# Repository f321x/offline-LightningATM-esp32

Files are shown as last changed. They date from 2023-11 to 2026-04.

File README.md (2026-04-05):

# DEPRECATED
This project has been replaced by a new implementation in https://github.com/f321x/offline-bitcoin-atm

# offline-LightningATM-esp32
Bitcoin ATM (coins only) with lightning network support, running offline on an esp32. 
The lightning network is a 2nd layer protocol on top of the bitcoin protocol enabling trustless transactions with instant settlement and cheap fees.

## Special thanks to
@21isenough and contributors for the 3d models and inspiration  
[RPi based Lightning ATM repo](https://github.com/21isenough/LightningATM)

LNBits, Ben Arc and Stepan Snigirev for the cryptograpy used to make this ATM working without internet connection  
[Fossa ATM repository](https://github.com/lnbits/fossa) | [LNBits Homepage](https://lnbits.com/) | [uBitcoin library](https://github.com/micro-bitcoin/uBitcoin)

Axel Hamburch for the very detailed guide in german language on assembly of the electronics  
[Ereignishorizont Blog](https://ereignishorizont.xyz/lightning-atm/)

## Used parts
All the parts are available on eBay and Aliexpress

* ESP32 NodeMCU Dev Board | Any "normal" esp32 dev board should do the job here | [Example](https://web.archive.org/web/20231202141343/https://www.berrybase.de/en/esp32-nodemcu-development-board)
* DC-DC Adjustable Step-up Boost Power Supply LM2587S 5V -> 12V | for the coin acceptor, runs on 12V [Example](https://de.aliexpress.com/item/32834930982.html)
* Waveshare 1.54 inch e-Paper Display Modul with SPI Interface | [Example](https://www.waveshare.com/1.54inch-e-paper-module.htm)
* Programmable Coin Acceptor (HX-616) - 6 Coin | [Example](https://de.aliexpress.com/item/1005005203759184.html)
* 10mm Metal Push Button Switch 3-6V with Yellow LED, Self-reset Momentary | [Example](https://de.aliexpress.com/item/1005004527235094.html)
* USB Type C socket | to plug in the power supply (i used a Raspberry Pi type C power supply) [Example](https://de.aliexpress.com/item/1005005347655323.html)
* Little Mosfet modules ("15A 400W MOS FET Trigger") | To block the coin acceptor at certain points [Example](https://de.aliexpress.com/item/33038160184.html)
* Orange PLA Filament for the 3D Printer | [Example](https://us.polymaker.com/products/polylite-pla)
* Jumper Wires | [Example](https://de.aliexpress.com/item/1005005945668553.html)
* Heat-Set Threaded Inserts M3 | [Example](https://www.prusa3d.com/product/threaded-inserts-m3-standard-100-pcs/)

All in all would calculate around $100 for the neccessary parts

# Assembly Instructions for Lightning ATM

## 1. Connecting the Waveshare 1.54 inch Display to the ESP32

Begin by connecting the Waveshare display to the ESP32 using the following pin assignments:

| Display Pins | ESP32 GPIO |
|---|---|
| Busy | 27 |
| RST | 33 |
| DC | 25 |
| CS | 26 |
| CLK | SCK = 18 |
| DIN | MOSI = 23  |
| GND | GND |
| 3.3V | 3.3V |

## 2. Programming the Coin Acceptor

Ensure to adjust the voltage of the step-up converter before connecting the coin acceptor. Detailed programming instructions are available in the following guides:
- [Coin Acceptor Programming Guide (English)](https://github.com/21isenough/LightningATM/blob/master/docs/guide/coin_validator.md)
- [Coin Acceptor Programming Guide (German)](https://ereignishorizont.xyz/lightning-atm/)

## 3. Connecting the Coin Acceptor to the ESP32

- For the Coin <-> Pin 17 connection, use a cable as short as possible.
- Short circuit the two pins below the switch on the coin acceptor with the MOSFET on GND IN and GND OUT.
- Connect the MOSFET GND pin to the ESP32 GND and the PWM pin to the pin specified in `include/lightning_atm.h`.

| Periphery Pin | ESP32 GPIO |
|---|---|
| Coin Acceptor 'Coin Pin' | 17 |
| Mosfet PWM Pin | 16 |
| Mosfet GND Pin | GND |

## 4. Connecting the LED Button

Connect the LED Button to the ESP32 according to the pin assignments specified in `include/lightning_atm.h`:

| Periphery Pin | ESP32 GPIO |
|---|---|
| Button LED Pin (+) | 21 |
| Button LED Pin (-) | GND |
| Button PIN 1 | 32 |
| Button PIN 2 | GND |

For wiring inspiration and guidance, refer to [Lightning ATM Documentation](https://github.com/21isenough/LightningATM/tree/master/docs).

## 5. Circuit Diagram

Below are two possible wiring options. Depending on which ESP32 type and display / driver board you are using. 

1. Standard ESP32 with separate display / driver board

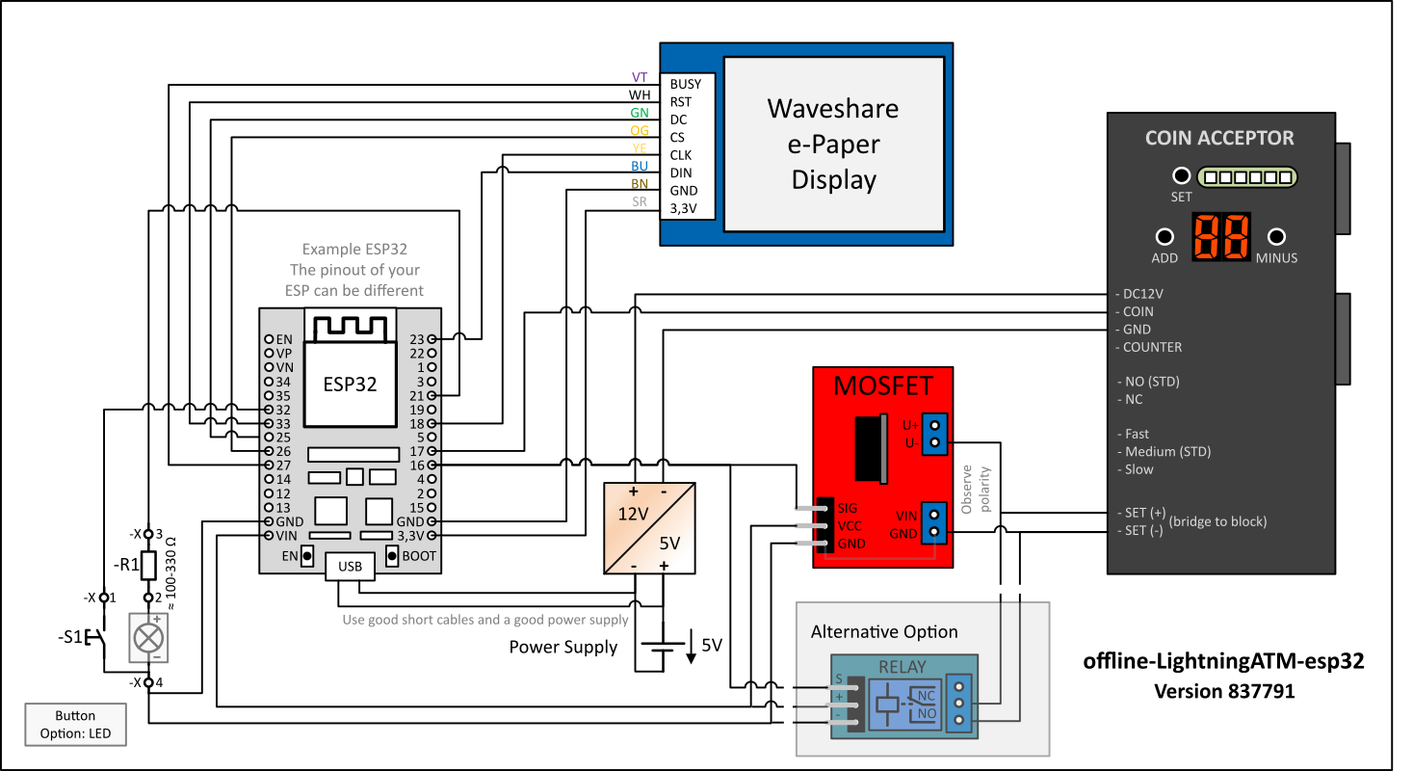
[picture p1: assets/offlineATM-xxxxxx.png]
Wiring - Circuit Diagram Normal ESP32


2. Waveshare ESP32 with integrated driver board and separate display

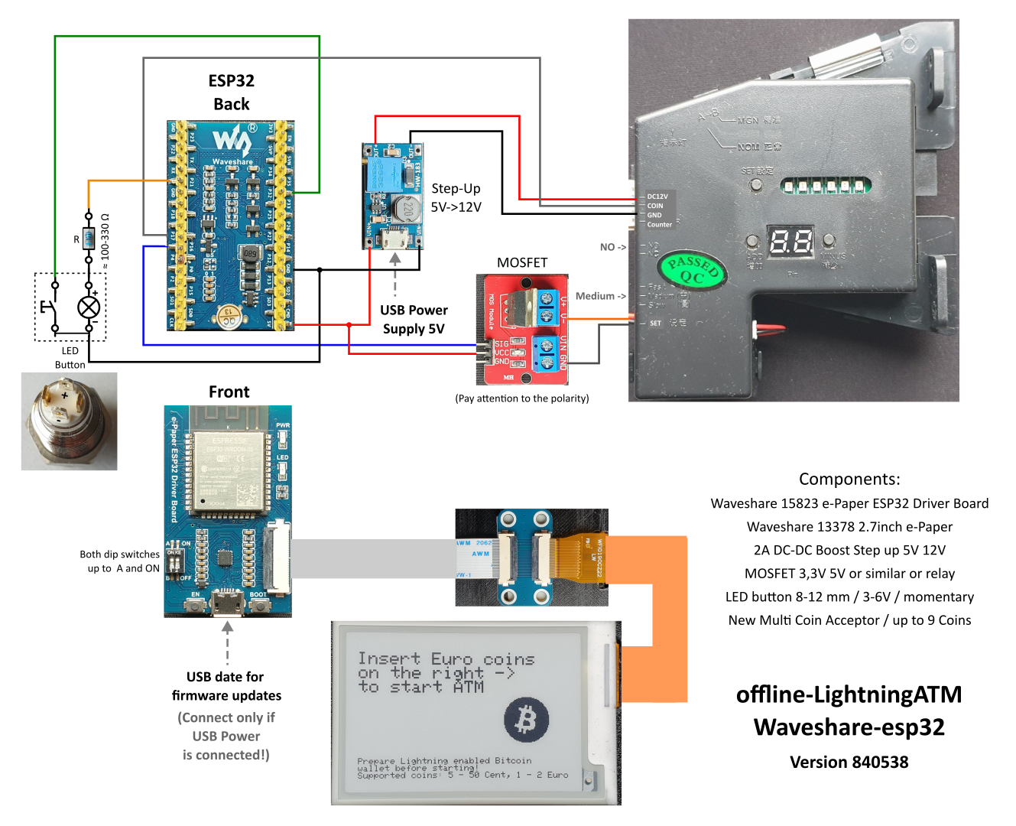
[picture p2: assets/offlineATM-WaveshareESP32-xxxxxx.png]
Wiring - Circuit Diagram Waveshare ESP32


## Setup software

1. Install VSCode and the PlattformIO IDE Extension.
2. Clone this repository and open it as PlattformIO Project.
3. Create an [LNbits](https://legend.lnbits.com/) wallet. Add the LNURLDevice extension and create a new LNURLDevice instance with ATM.

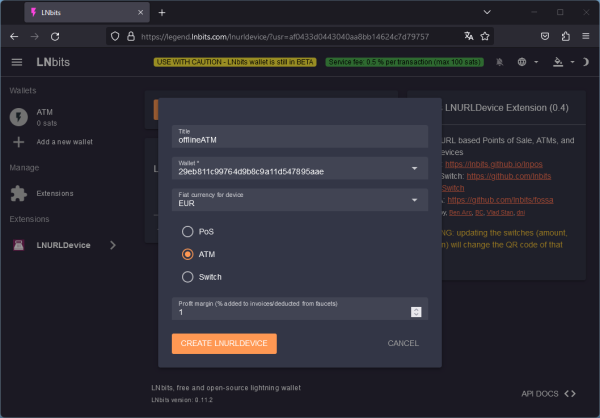
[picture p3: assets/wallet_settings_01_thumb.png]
wallet_settings_02_thumb
    

4. Copy the LNURLDevice Settings String and paste it into the code under “include/lighting_atm.h” under “USER ACTION”.

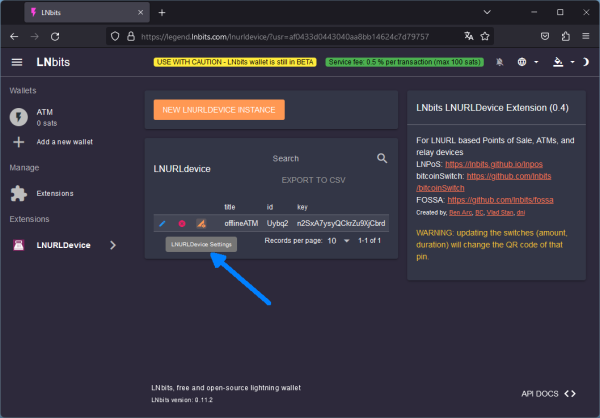
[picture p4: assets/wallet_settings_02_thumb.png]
wallet_settings_02_thumb
    

5. Flash the software on the esp32. You may have to disconnect the ESP32 from the step up converter before connecting it to the computer to prevent faults, or power it up with the power supply and use an usb isolator.

If you need help ask me on Nostr @npub1z9n5ktfjrlpyywds9t7ljekr9cm9jjnzs27h702te5fy8p2c4dgs5zvycf

If this software and guide provided value to you feel free to send some sats to x@lnaddress.com

## Images

Standard ESP32

PXL_20231126_162906807 MP_1

Waveshare ESP32
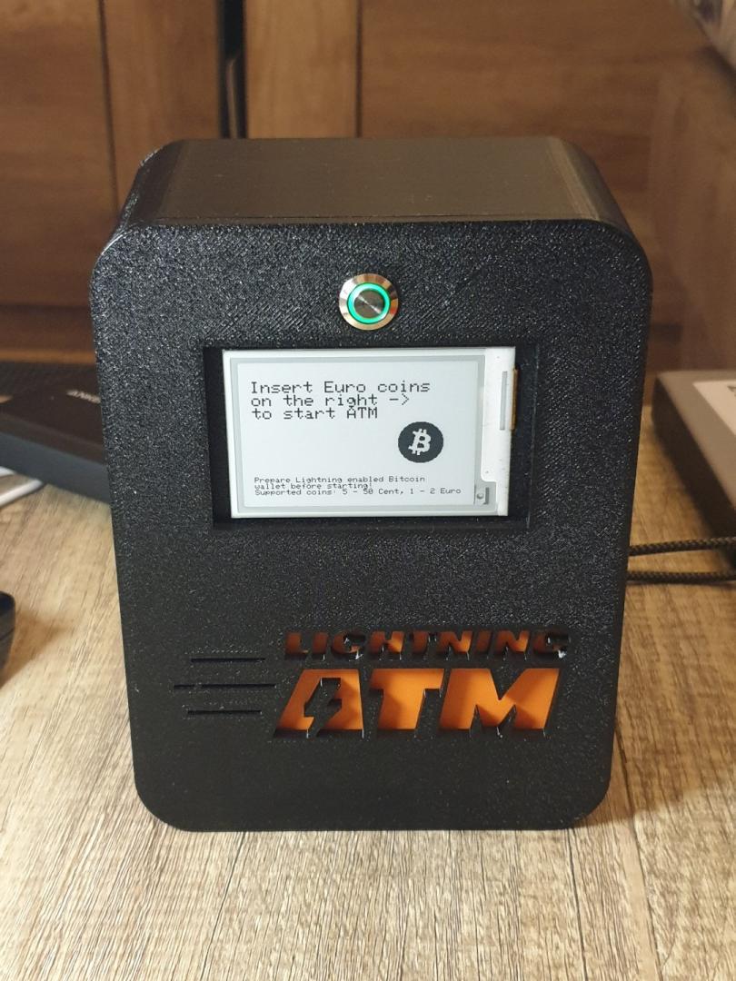
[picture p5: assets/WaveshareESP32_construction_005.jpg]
Construction - Waveshare ESP32

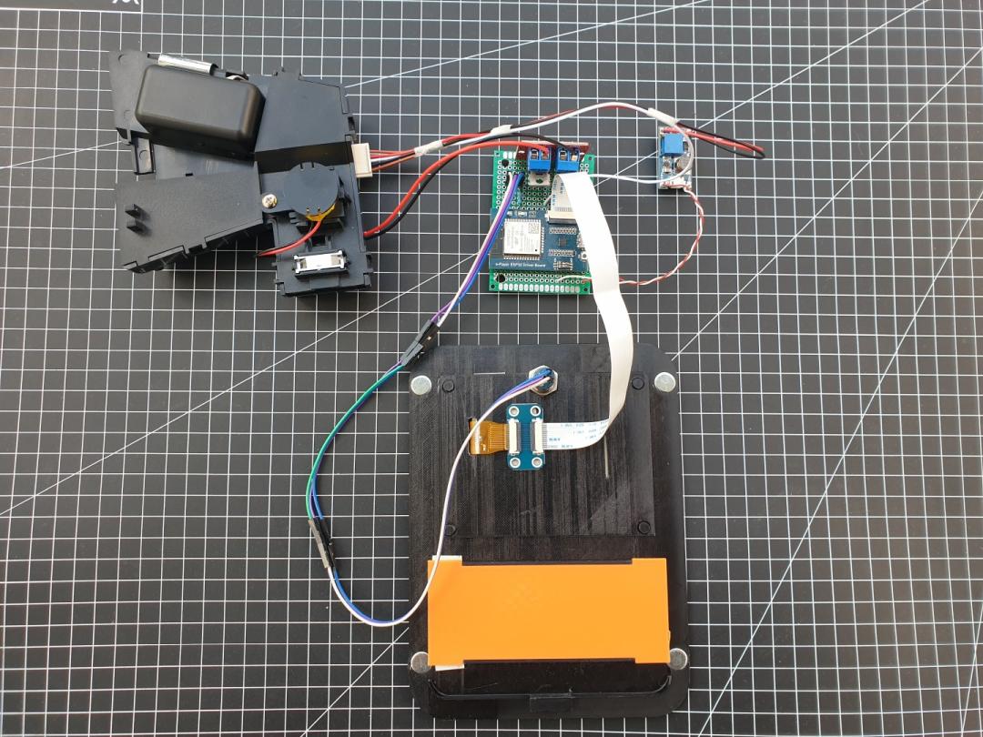
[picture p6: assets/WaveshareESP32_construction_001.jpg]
Construction - Waveshare ESP32

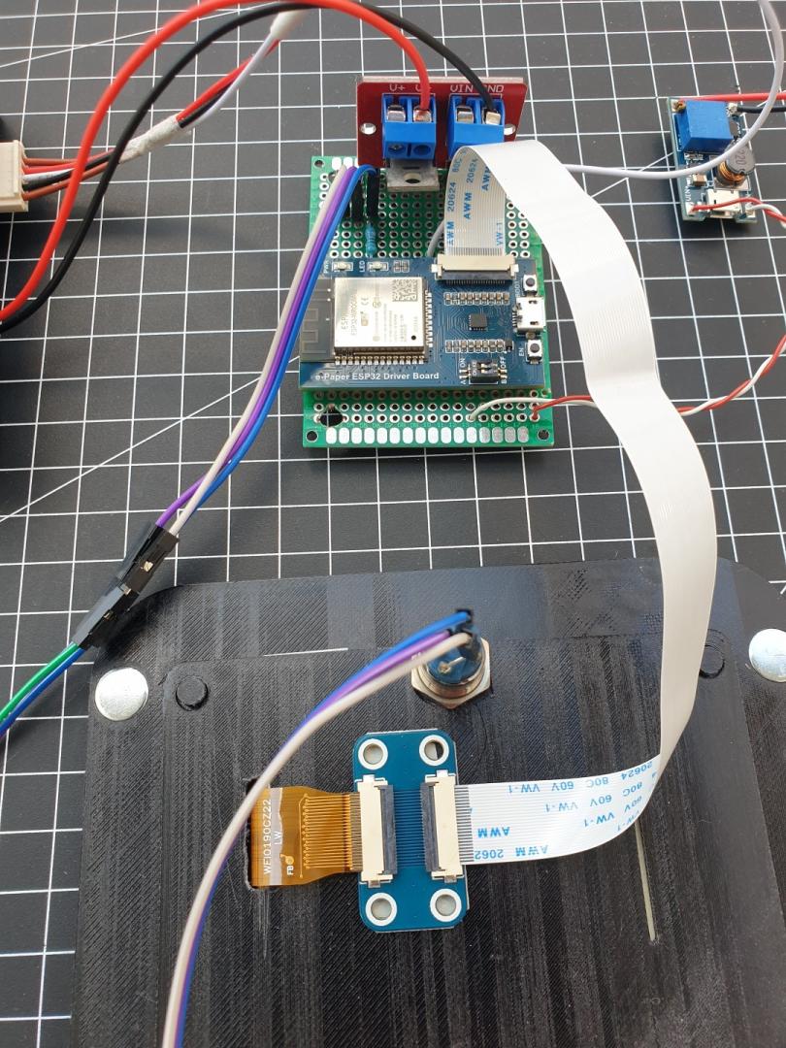
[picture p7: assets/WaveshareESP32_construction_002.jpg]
Construction - Waveshare ESP32

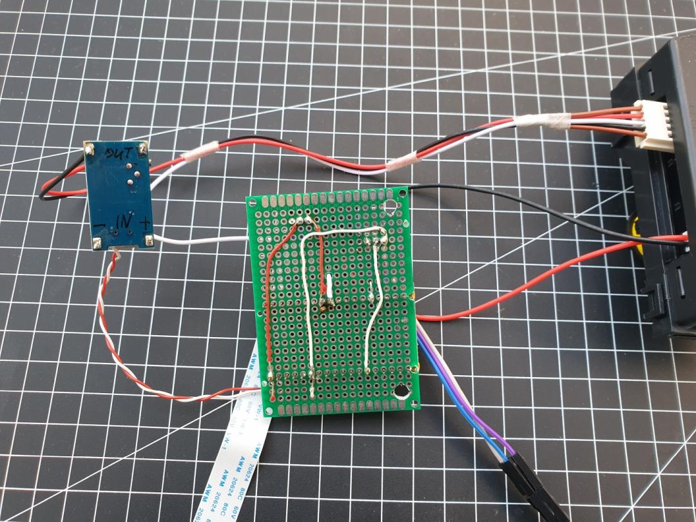
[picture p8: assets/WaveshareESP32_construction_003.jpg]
Construction - Waveshare ESP32

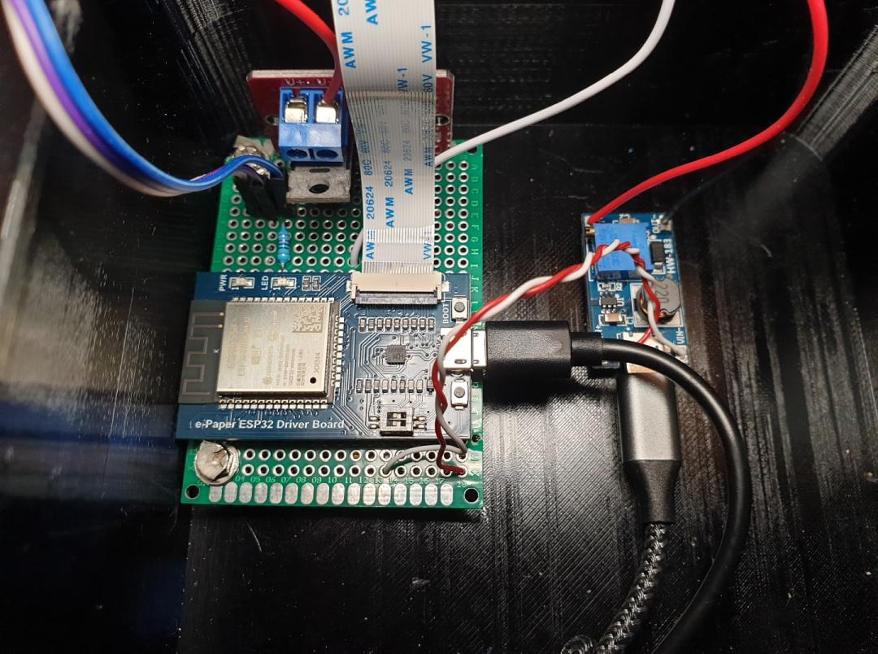
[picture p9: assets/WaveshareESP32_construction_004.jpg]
Construction - Waveshare ESP32


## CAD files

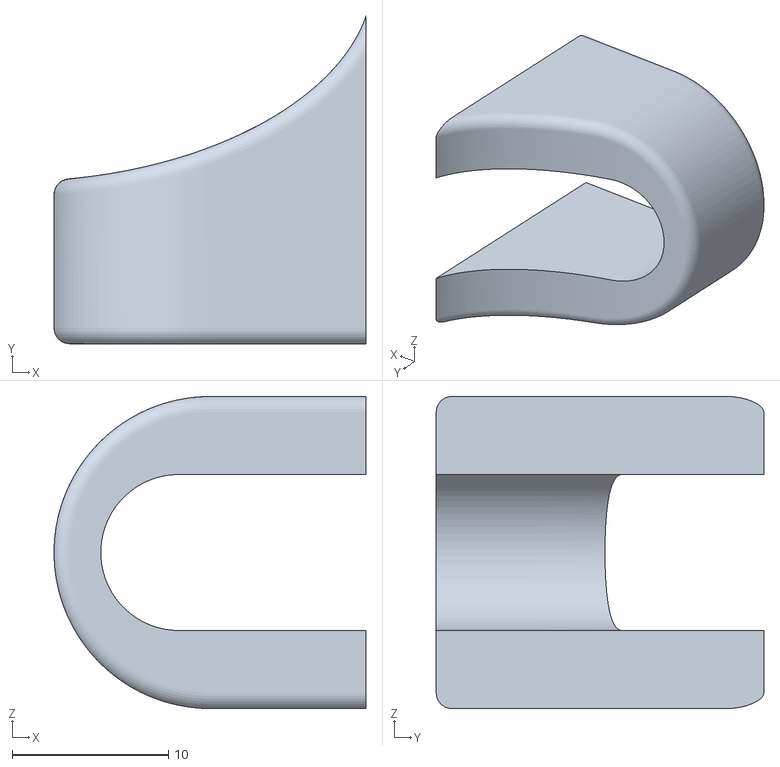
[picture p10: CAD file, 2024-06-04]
3d-print-model/CCatch v3.stl
20.0 x 21.0 x 20.0

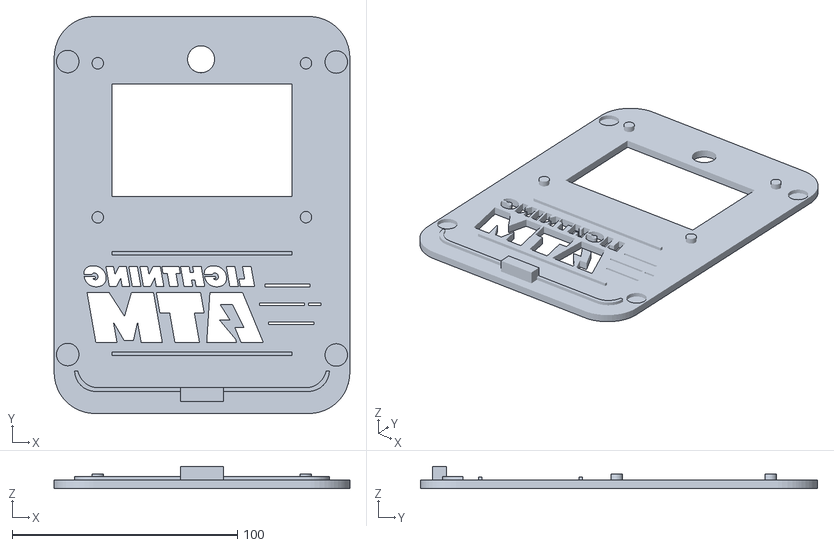
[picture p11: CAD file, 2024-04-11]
3d-print-model/Magnet Case - with button preferred/Front Magnet - with 12 mm hole.stl
131.2 x 176.2 x 9.96

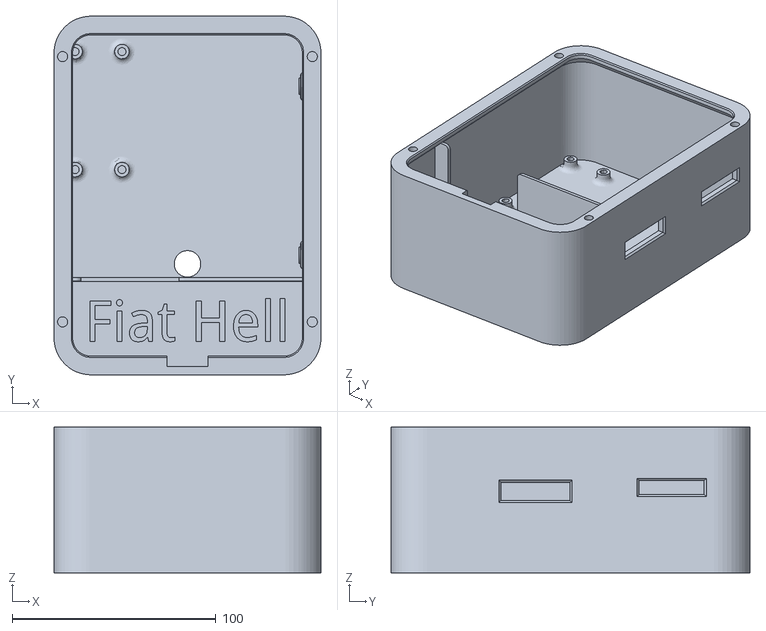
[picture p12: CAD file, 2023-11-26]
3d-print-model/Magnet Case - with button preferred/Case Magnet.stl
131.2 x 176.2 x 71.7

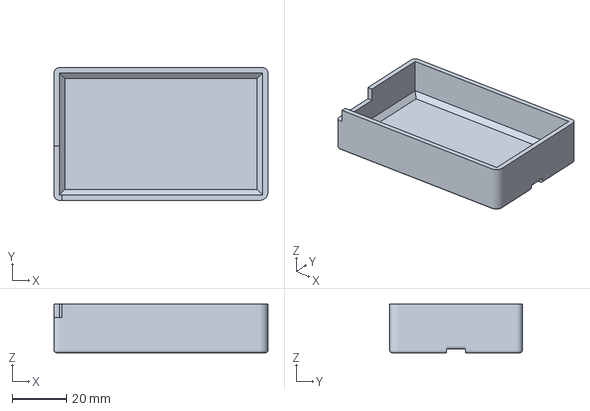
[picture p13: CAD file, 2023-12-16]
3d-print-model/transport_screen_cover.3mf
79.0 x 49.0 x 18.0 mm

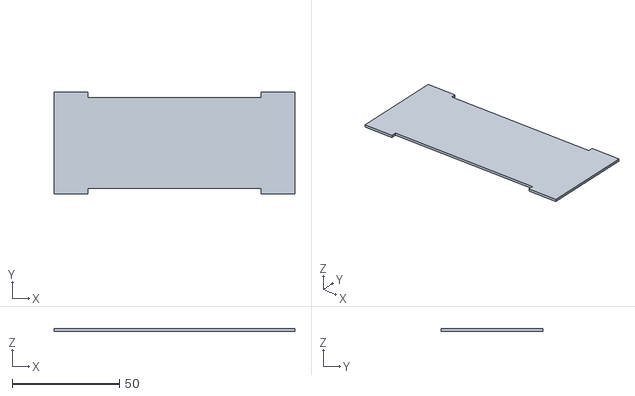
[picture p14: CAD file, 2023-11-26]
3d-print-model/Magnet Case - with button preferred/Logo Backplate Magnet.stl
112.3 x 47.6 x 1.20

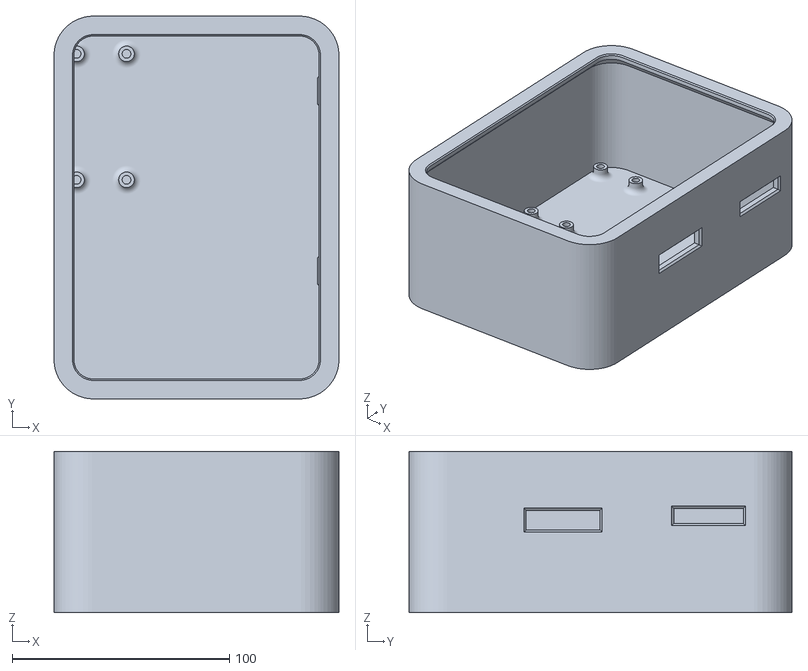
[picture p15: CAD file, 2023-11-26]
3d-print-model/Shell_v1_NoSupp.stl
131.2 x 176.2 x 74.2

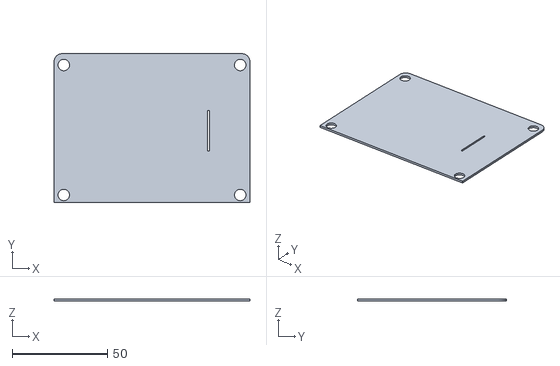
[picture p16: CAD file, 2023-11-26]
3d-print-model/Magnet Case - with button preferred/Screen Backplate Magnet.stl
103.0 x 78.1 x 1.20

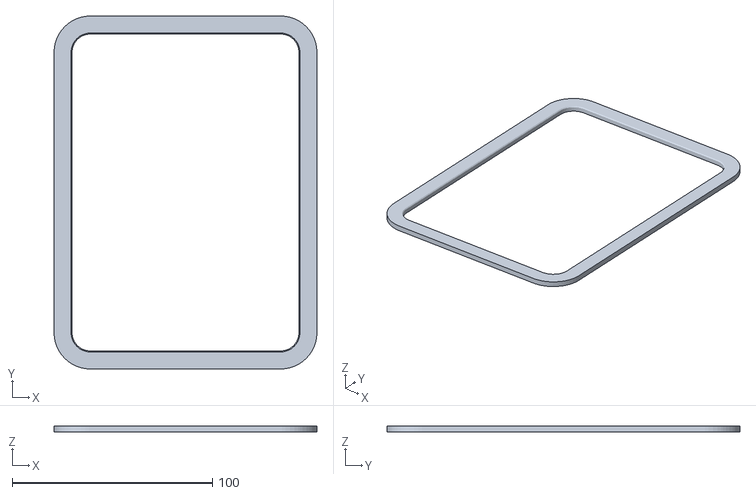
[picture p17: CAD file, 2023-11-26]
3d-print-model/optional_Mounting_Rim_v1_NoSupp.stl
131.2 x 176.2 x 3.00

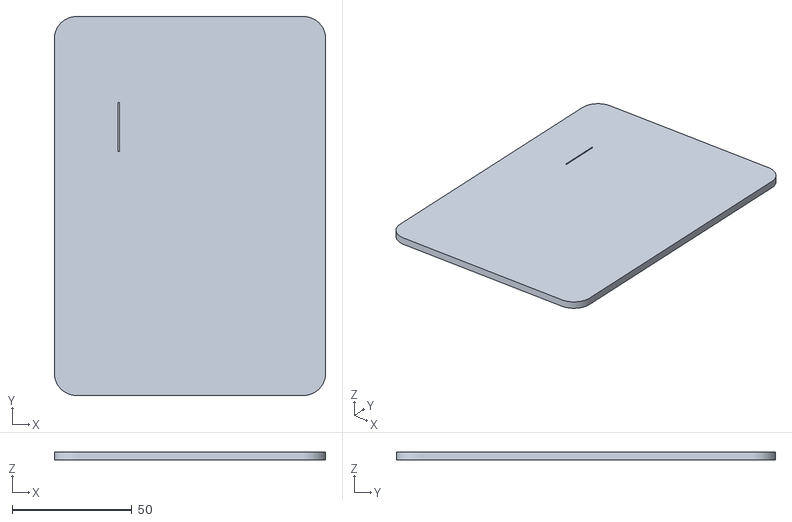
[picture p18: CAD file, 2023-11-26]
3d-print-model/Back_Lid_THICKER_v1_NoSupp.stl
113.4 x 158.4 x 3.50

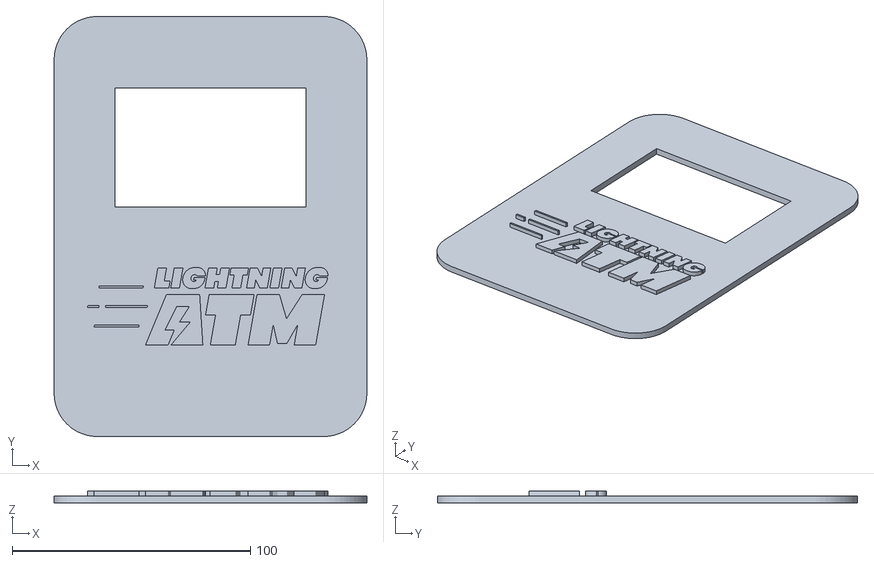
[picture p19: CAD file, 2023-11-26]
3d-print-model/Top_Lid_with_Logo_v1_NoSupp.stl
131.2 x 176.2 x 5.00

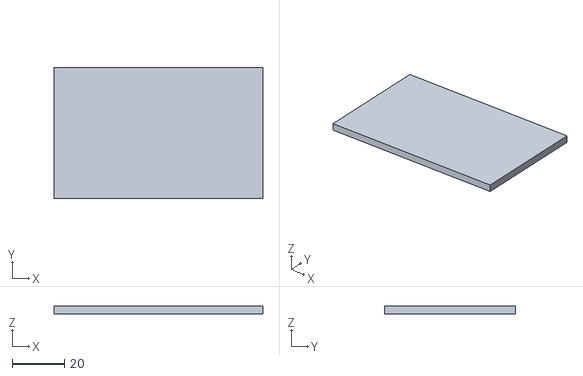
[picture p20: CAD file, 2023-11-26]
3d-print-model/Front_Glass_v1_NoSupp.stl
80.2 x 50.2 x 3.00

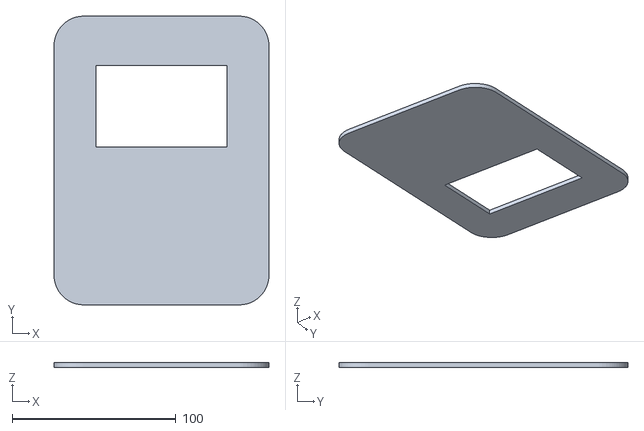
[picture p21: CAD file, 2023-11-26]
3d-print-model/Top_Lid_No_Logo_v1_NoSupp.stl
131.2 x 176.2 x 3.00

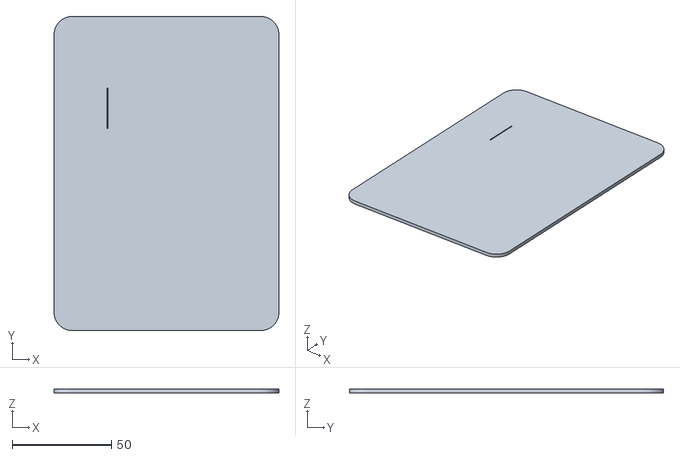
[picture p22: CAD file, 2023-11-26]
3d-print-model/Back_Lid_NORMAL_v1_NoSupp.stl
113.4 x 158.4 x 2.00

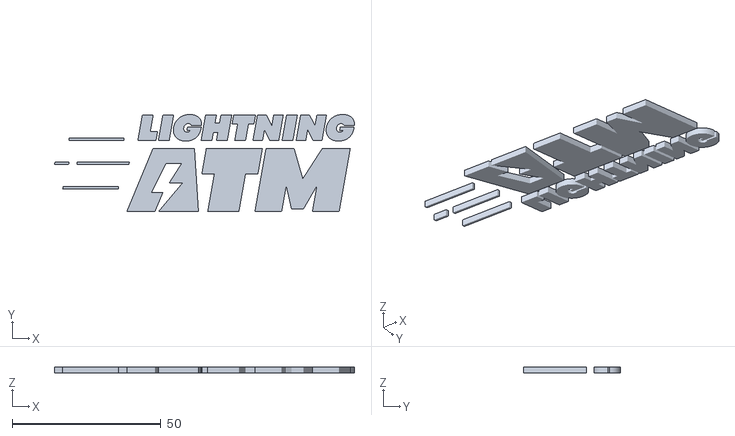
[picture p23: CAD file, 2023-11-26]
3d-print-model/just_logo.stl
100.9 x 32.6 x 2.00

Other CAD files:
3d-print-model/Magnet Case/Front Magnet.stl

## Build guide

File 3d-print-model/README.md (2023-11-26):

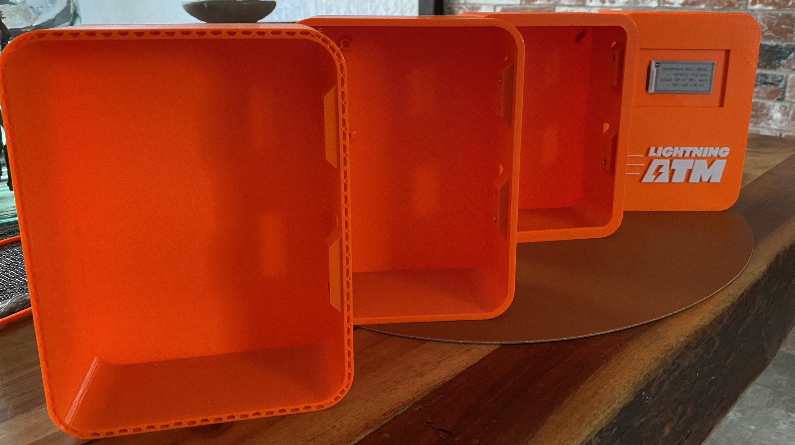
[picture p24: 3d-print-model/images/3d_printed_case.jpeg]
 <br>

# 3D Printed L-ATM Case PE-Edition

Below files can be used to print a case, which lowers your overall costs. The models can be printed  without any supports.

This is the first version and is designed to be used with inserts to mount the Coin-Acceptor as well as the Rasbperry-Pi Zero. For the Coin Acceptor use **M3** inserts [(Amazon)](https://amzn.to/35eNkgj), for the Raspberry-Pi **M2.5** [(Amazon)](https://amzn.to/2HjF0Uo) inserts are needed.
The Lids holds by friction fit.

For the case **needed** are 3 Parts: 
- **Shell**
  
- **Back Lid**
  - two versions
    - normal with 2mm thick plate
    - thicker with 3mm thick plate
- **Top Lid**
  - there are two separate versions:
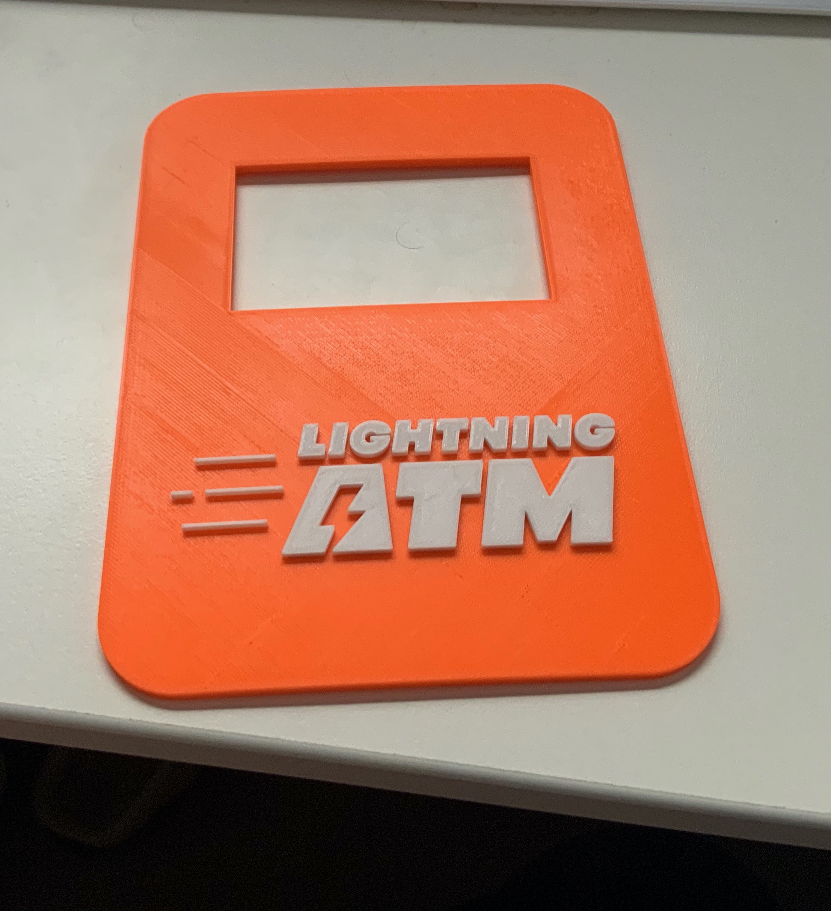
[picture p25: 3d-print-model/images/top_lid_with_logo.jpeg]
    - with Lightning-Logo, *for dual color print add a **color change at Z 3.00 mm***. 
    - without any logo
- Mounting Rim
  - optional but *recommended* to properly glue the Top Lid onto the Back Lid.

1. Print Shell / Back Lid / Top Lid / Mounting Rim
2. Use soldering iron to:
   1. Add M3 Inserts into Coin Acceptor holes 
   2. Add M2.5 Inserts into Raspberry holes
   
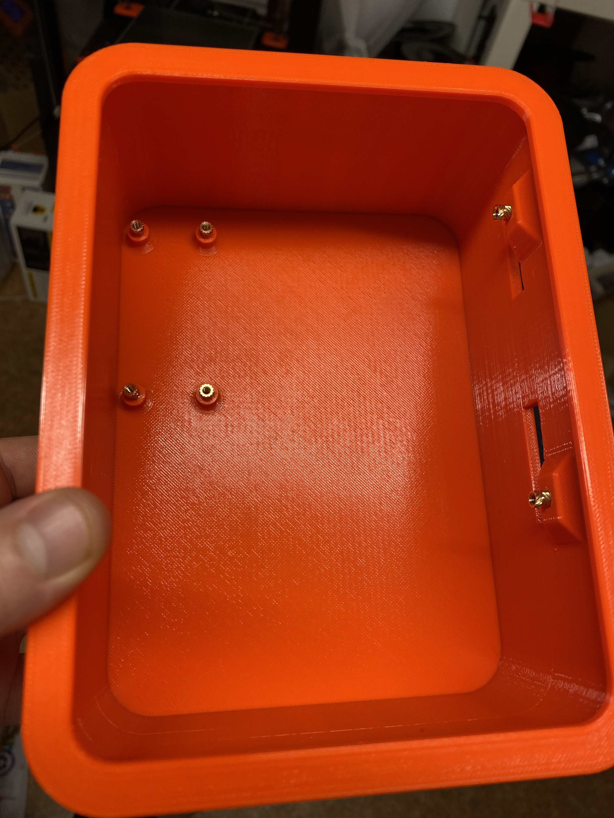
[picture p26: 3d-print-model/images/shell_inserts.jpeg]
   <br> <br>
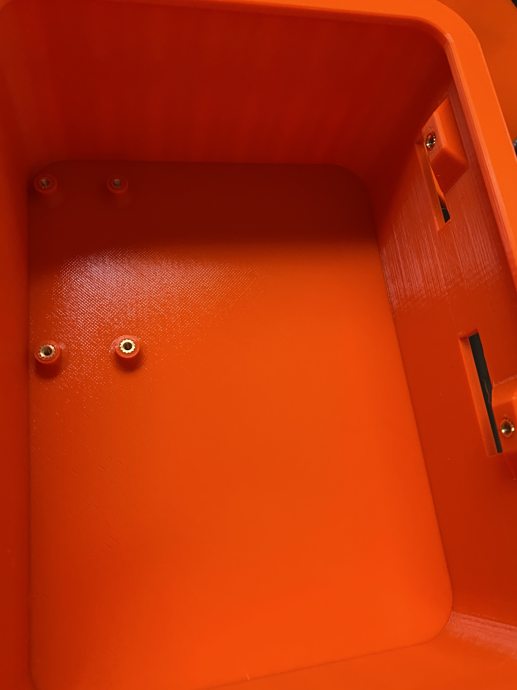
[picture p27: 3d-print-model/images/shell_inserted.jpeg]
   
   
3. If you have printed the *Mounting Rim* put it around the BackLid
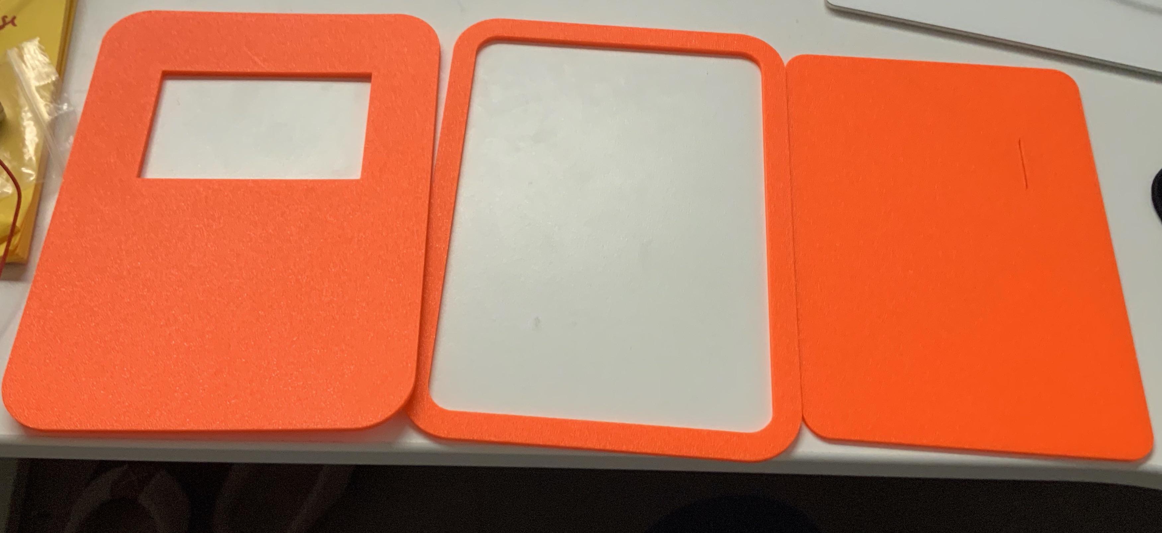
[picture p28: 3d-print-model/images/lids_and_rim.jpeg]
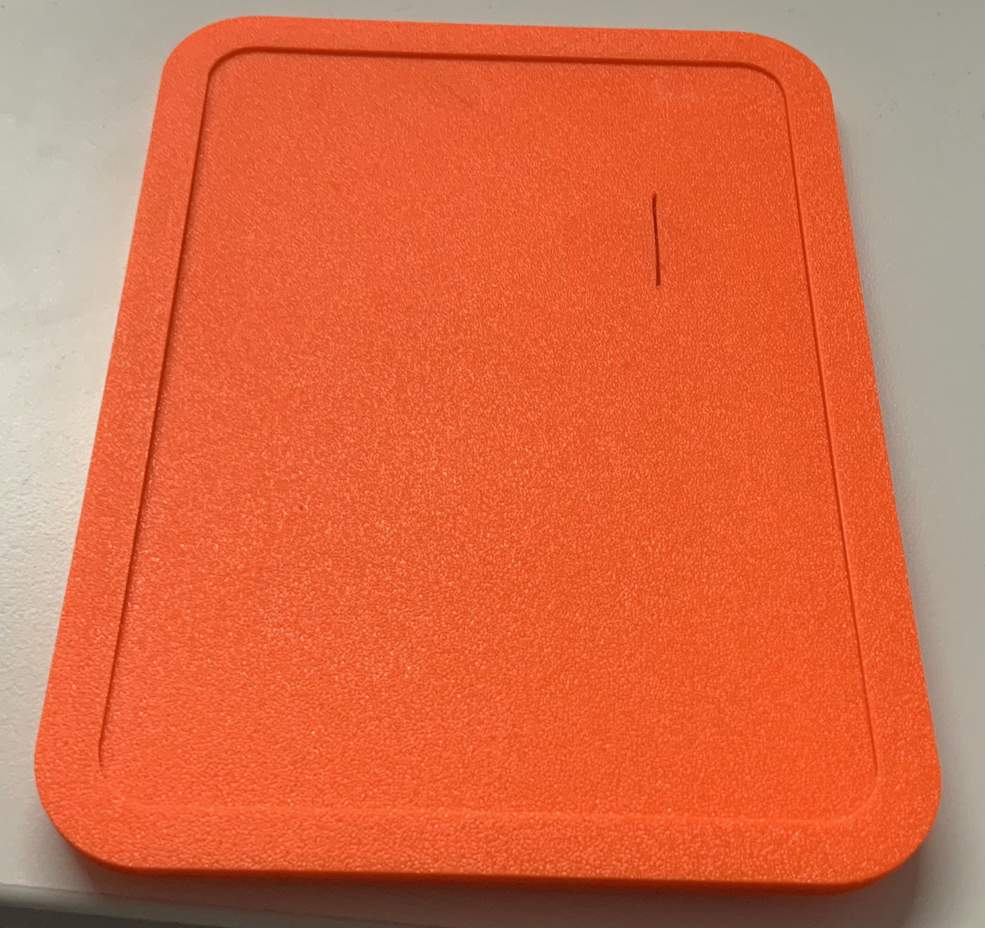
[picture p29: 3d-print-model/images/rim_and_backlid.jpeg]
<br> <br> 
4. put glue on the Top Lid and use something to press both together
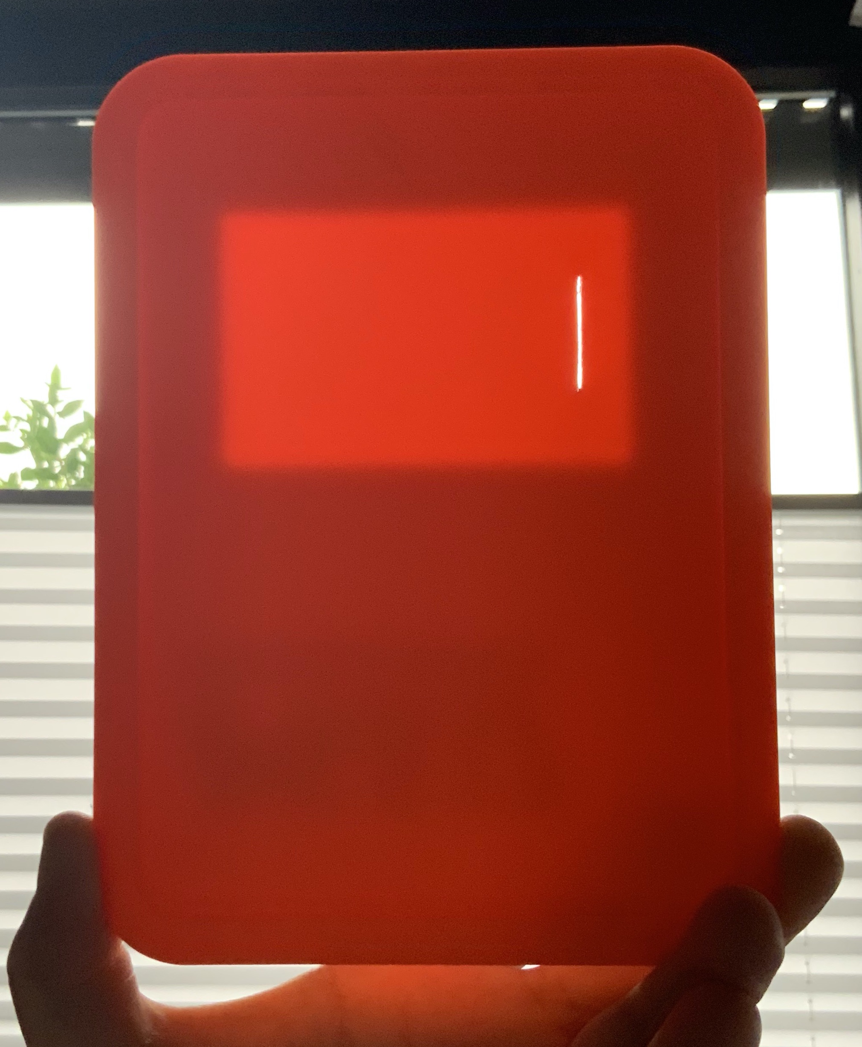
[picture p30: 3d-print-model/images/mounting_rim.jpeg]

5. this is what it should look like without the rim
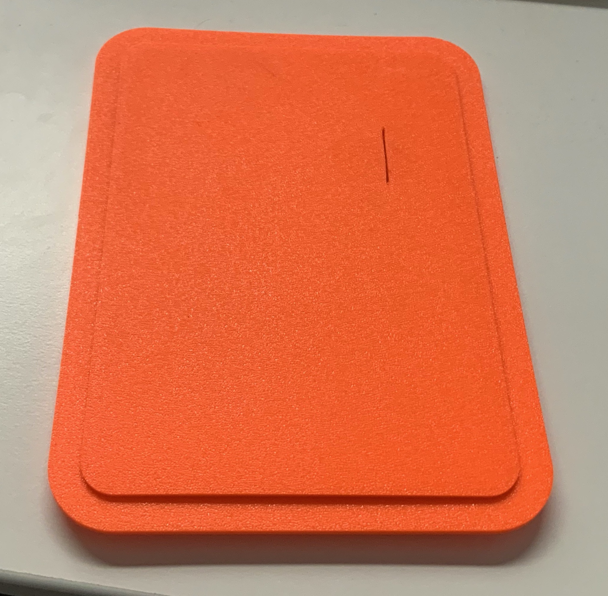
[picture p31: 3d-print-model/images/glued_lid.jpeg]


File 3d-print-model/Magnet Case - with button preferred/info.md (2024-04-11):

I have added new 3D models, which can be supplemented with magnets so that you no longer have to attach the front panel to the case with a rubber band. You can find the procedure and more details in my Twitter Thread ...

Magnets: 5x5mm round nickel plate: https://www.supermagnete.ch/scheibenmagnete-neodym/scheibenmagnet-5mm-5mm_S-05-05-N
Metal plates: 2x10mm self-adhesive: https://www.supermagnete.ch/magnethaftgruende-selbstklebend/metallscheiben-selbstklebend-10mm_PAS-10

For more information please DM me on Twitter or Telegram! @Nicolas_b58

Update axelhamburch 838776:
In this version, the front panel has a hole for a 12 mm LED button in the upper area of the front panel. You will need a drill and possibly a file for the "screen backplate". Depending on which display you use, you may also need this for a feed-through for the ribbon cable.

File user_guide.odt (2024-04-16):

Lightning ATM guide

What is „Lightning“?

Lightning is a protocol layer on top of the Bitcoin protocol, like HTTP on TCP/IP, enabling instant, trustless and cheap bitcoin transactions.

How to use Lightning⚡?

You need a Bitcoin Wallet that supports the Lightning protocol. There are many different ones for various use cases. You can hold your own private keys, which is recommended for more advanced users (e.g. “Phoenix Wallet”) but involves higher setup cost, or use a trusted, convenient service.

For the beginning go to mutinywallet.com and download the app. Select a federation, save the backup words on a piece of paper and you’re set!

How to use the ATM?

Insert Euro coins >= 5ct, press button once done, scan QR code, done!

1 Satoshi == 0.00000001 ₿

Problems😡

Contact XXX, i’ll fix it.

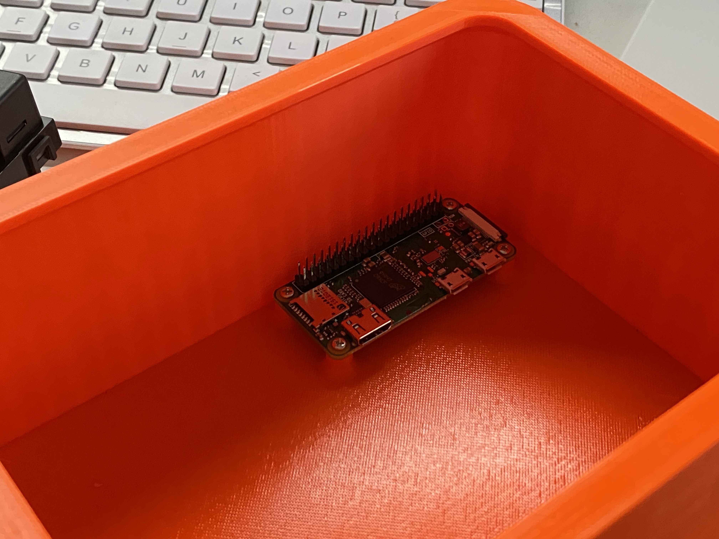
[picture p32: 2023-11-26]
3d-print-model/images/shell_with_mounted_pi.jpeg

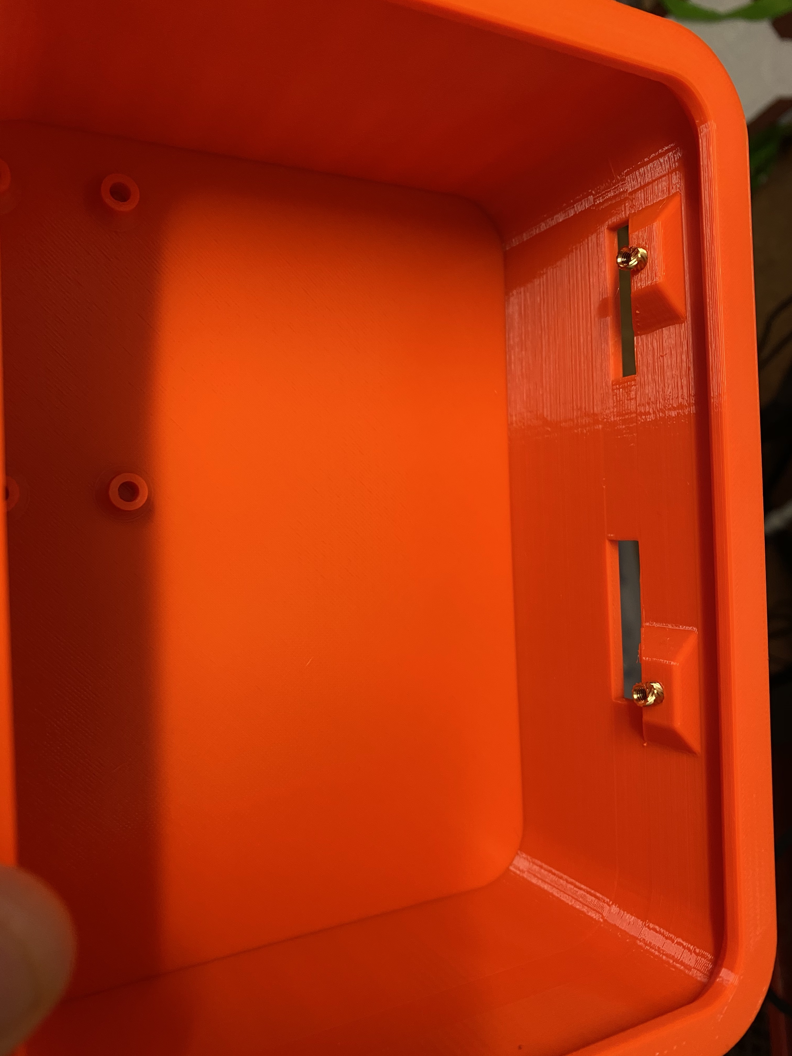
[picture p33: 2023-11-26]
3d-print-model/images/shell_m3_inserts.jpeg

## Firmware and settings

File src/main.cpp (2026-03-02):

#include "lightning_atm.hpp"

const unsigned int COINS[] = { 0, 0, 5, 10, 20, 50, 100, 200, 1, 2 };
bool button_pressed = false;
unsigned int inserted_cents = 0;
unsigned long long time_last_press = millis();
String baseURLATM;
String secretATM;
String currencyATM;
bool fossaMode = false;  // set automatically from lnurlDeviceString in setup()

// *** for Waveshare ESP32 Driver board *** //
#if defined(ESP32) && defined(USE_HSPI_FOR_EPD)
SPIClass hspi(HSPI);
#endif
// *** end Waveshare ESP32 Driver board *** //


void setup()
{
  initialize_display(); // connection to the e-ink display
  Serial.begin(9600);
  // *** for Waveshare ESP32 Driver board *** //
#if defined(ESP32) && defined(USE_HSPI_FOR_EPD)
  hspi.begin(13, 12, 14, 15); // remap hspi for EPD (swap pins)
  display.epd2.selectSPI(hspi, SPISettings(4000000, MSBFIRST, SPI_MODE0));
#endif
  // *** end Waveshare ESP32 Driver board *** //
  if (DEBUG_MODE)                                           // serial connection for debugging over USB
  {
    sleep(3);
    Serial.println("Setup with debug mode...");             // for monitoring with serial monitor to debug
    Serial.println("Selected display type: " + display_type);
  }
  pinMode(COIN_PIN, INPUT_PULLUP);                          // coin acceptor input
  pinMode(LED_BUTTON_PIN, OUTPUT);                          // LED of the LED Button
  pinMode(BUTTON_PIN, INPUT_PULLUP);                        // Button
  pinMode(MOSFET_PIN, OUTPUT);                              // mosfet relay to block the coin acceptor
  digitalWrite(MOSFET_PIN, LOW);                            // set it low to accept coins, high to block coins
  attachInterrupt(BUTTON_PIN, button_pressed_itr, FALLING); // interrupt, will set button_pressed to true when button is pressed
  home_screen();                                            // will show first screen
  digitalWrite(LED_BUTTON_PIN, HIGH);                       // light up the led
  baseURLATM = getValue(lnurlDeviceString, ',', 0);         // setup wallet data from string
  secretATM = getValue(lnurlDeviceString, ',', 1);
  currencyATM = getValue(lnurlDeviceString, ',', 2);
  fossaMode = (lnurlDeviceString.indexOf("/fossa/") >= 0); // auto-detect backend from URL
}

void loop()
{
  unsigned int pulses = 0;
  unsigned long long time_last_press;

  pulses = detect_coin(); // detect_coin() is a loop to detect the input of coins, will return the amount of pulses
  if (pulses >= 2 && pulses <= 9)
  {
    digitalWrite(MOSFET_PIN, HIGH);
    digitalWrite(LED_BUTTON_PIN, LOW);
    inserted_cents += COINS[pulses];
    show_inserted_amount(inserted_cents);
  }
  else if (button_pressed && inserted_cents > 0)
  {
    digitalWrite(MOSFET_PIN, HIGH);
    button_pressed = false;
    try {
      // makeLNURL can raise
      String lnurl = makeLNURL(inserted_cents);
      qr_withdrawl_screen(lnurl.c_str());
      wait_for_user_to_scan();
    }
    catch (const std::exception& e) {
      Serial.println(e.what());
    }
    digitalWrite(LED_BUTTON_PIN, HIGH);
    home_screen();
    digitalWrite(MOSFET_PIN, LOW);
    inserted_cents = 0;
  }
  else if (button_pressed && !pulses && !inserted_cents) // to clean the screen (for storage), press the button several times
  {
    int press_counter = 0;

    button_pressed = false;
    time_last_press = millis();
    while ((millis() - time_last_press) < 4000 && press_counter < 6)
    {
      if (button_pressed)
      {
        if (DEBUG_MODE)
          Serial.println("Button pressed");
        time_last_press = millis();
        button_pressed = false;
        press_counter++;
        delay(500);
      }
    }
    if (press_counter > 5)
    {
      if (DEBUG_MODE)
        Serial.println("Button pressed over 5 times, will clean screen...");
      digitalWrite(LED_BUTTON_PIN, LOW);
      clean_screen();
      display_sleep();
      delay(30000);
      home_screen();
    }
  }
}

// function to handle the button interrupt
void IRAM_ATTR button_pressed_itr()
{
  button_pressed = true;
}

// blocking loop which is called when the qr code is shown
void wait_for_user_to_scan()
{
  unsigned long long time;
  bool light_on;

  if (DEBUG_MODE)
    Serial.println("Waiting for user to scan qr code and press button...");
  light_on = true;
  time = millis();  // save start time
  digitalWrite(LED_BUTTON_PIN, HIGH);  // light up the led
  delay(5000);
  button_pressed = false;
  Serial.println("wait for user to press button or 10 minutes to go back to home screen");
  while (!button_pressed && (millis() - time) < 600000)
  {
    if (!light_on && (millis() - time) > 30000)
    {
      digitalWrite(LED_BUTTON_PIN, HIGH);
      light_on = true;
    }
    else if (light_on && (millis() - time) > 30000)
    {
      digitalWrite(LED_BUTTON_PIN, LOW);
      light_on = false;
    }
    delay(500);
  }
  Serial.println("Exit waiting");
}

unsigned int detect_coin()
{
  unsigned long last_pulse;
  unsigned int pulses;
  bool prev_value;
  bool read_value;
  unsigned long entering_time;
  unsigned long current_time;

  if (DEBUG_MODE)
    Serial.println("Starting coin detection...");
  pulses = 0;
  read_value = 1;
  prev_value = digitalRead(COIN_PIN);
  digitalWrite(LED_BUTTON_PIN, HIGH);
  digitalWrite(MOSFET_PIN, LOW);
  button_pressed = false;
  entering_time = millis();
  while (true && !button_pressed)
  {
    read_value = digitalRead(COIN_PIN);
    if (read_value != prev_value && !read_value)
    {
      delay(35);
      read_value = digitalRead(COIN_PIN);
      if (!read_value)
      {
        pulses++;
        last_pulse = millis();
        digitalWrite(MOSFET_PIN, HIGH);
      }
    }
    prev_value = read_value;
    current_time = millis();
    if (pulses > 0 && (current_time - last_pulse > PULSE_TIMEOUT))
    {
      break;
    }
    else if (pulses == 0 && ((current_time - entering_time) > 43200000) // refreshes the screen every 12h
      && inserted_cents == 0)
    {
      clean_screen();
      delay(10000);
      entering_time = millis();
      home_screen();
    }
    else if (inserted_cents > 0 && (current_time - entering_time) > 360000) // break the loop if no new coin is inserted for some time
      button_pressed = true;
  }
  if (DEBUG_MODE)
    Serial.println("Pulses: " + String(pulses));
  if (button_pressed)
  {
    if (DEBUG_MODE)
      Serial.println("Button pressed, stopping coin detection");
    return (0);
  }
  return (pulses);
}

/*
** DISPLAY UTILS
*/

// sleep is to put the screen in hibernation mode for longer static frames
void display_sleep()
{
  if (display_type == "GxEPD2_150_BN")
    display.hibernate();
  else if (display_type == "GxEPD2_270")
    display.hibernate();
  else if (display_type == "GxEPD2_270_GDEY027T91")
    display.hibernate();
  else if (display_type == "GxEPD2_213_B74")
    display.hibernate();
  else if (display_type == "GxEPD2_213_flex")
    display.hibernate();
  else
    Serial.println("No suitable display class defined.");
}

void initialize_display()
{
  if (display_type == "GxEPD2_150_BN")
    display.init(115200, true, 2, false);
  else if (display_type == "GxEPD2_270")
    display.init(115200, true, 2, false);
  else if (display_type == "GxEPD2_270_GDEY027T91")
    display.init(115200, true, 2, false);
  else if (display_type == "GxEPD2_213_B74")
    display.init(115200, true, 2, false);
  else if (display_type == "GxEPD2_213_flex")
    display.init(115200, true, 2, false);
  else
    Serial.println("No suitable display class defined.");
}

void home_screen()
{
  if (display_type == "GxEPD2_150_BN")
    home_screen_waveshare_1_54();
  else if (display_type == "GxEPD2_270")
    home_screen_waveshare_2_7();
  else if (display_type == "GxEPD2_270_GDEY027T91")
    home_screen_waveshare_2_7();
  else if (display_type == "GxEPD2_213_B74")
    home_screen_waveshare_2_13();
  else if (display_type == "GxEPD2_213_flex")
    home_screen_waveshare_2_13_flex();
  else
    Serial.println("No suitable display class defined.");
  if (DEBUG_MODE)
    Serial.println("Home screen printed.");
}

void show_inserted_amount(int amount_in_cents)
{
  String amount_in_euro_string;

  amount_in_euro_string = get_amount_string(amount_in_cents);
  if (display_type == "GxEPD2_150_BN")
    show_inserted_amount_waveshare_1_54(amount_in_euro_string);
  else if (display_type == "GxEPD2_270")
    show_inserted_amount_waveshare_2_7(amount_in_euro_string);
  else if (display_type == "GxEPD2_270_GDEY027T91")
    show_inserted_amount_waveshare_2_7(amount_in_euro_string);
  else if (display_type == "GxEPD2_213_B74")
    show_inserted_amount_waveshare_2_13(amount_in_euro_string);
  else if (display_type == "GxEPD2_213_flex")
    show_inserted_amount_waveshare_2_13_flex(amount_in_euro_string);
  else
    Serial.println("No suitable display class defined.");
  if (DEBUG_MODE)
    Serial.println("New amount on screen.");
}

void qr_withdrawl_screen(const char* qr_content)
{
  if (display_type == "GxEPD2_150_BN")
    qr_withdrawl_screen_waveshare_1_54(qr_content);
  else if (display_type == "GxEPD2_270")
    qr_withdrawl_screen_waveshare_2_7(qr_content);
  else if (display_type == "GxEPD2_270_GDEY027T91")
    qr_withdrawl_screen_waveshare_2_7(qr_content);
  else if (display_type == "GxEPD2_213_B74")
    qr_withdrawl_screen_waveshare_2_13(qr_content);
  else if (display_type == "GxEPD2_213_flex")
    qr_withdrawl_screen_waveshare_2_13_flex(qr_content);
  else
    Serial.println("No suitable display class defined.");
  if (DEBUG_MODE)
    Serial.println("QR generated and Withdrawl screen printed.");
}


//  Called to clean the e-ink screen for storage over longer periods 
// by button presses on home screen
void clean_screen()
{
  if (DEBUG_MODE)
    Serial.println("Cleaning screen...");
  if (display_type == "GxEPD2_150_BN")
    clean_screen_waveshare_1_54();
  else if (display_type == "GxEPD2_270")
    clean_screen_waveshare_2_7();
  else if (display_type == "GxEPD2_270_GDEY027T91")
    clean_screen_waveshare_2_7();
  else if (display_type == "GxEPD2_213_B74")
    clean_screen_waveshare_2_13();
  else if (display_type == "GxEPD2_213_flex")
    clean_screen_waveshare_2_13_flex();
  else
    Serial.println("No suitable display class defined.");
}

// converts a cent amount to a String like "1.15 Euro"
String get_amount_string(int amount_in_cents)
{
  String euro;
  String cents;
  String return_value;
  int euro_value;
  int cent_remainder;

  euro_value = amount_in_cents / 100;
  cent_remainder = amount_in_cents % 100;
  euro = String(euro_value);
  if (cent_remainder > 9)
    cents = String(cent_remainder);
  else if (cent_remainder < 10)
    cents = "0" + String(cent_remainder);
  return_value = String(euro) + "." + String(cents) + " " + currencyATM;
  if (DEBUG_MODE)
    Serial.println("Calculated amount string: " + return_value);
  return (return_value);
}

String makeLNURL(float total)
{
  if (fossaMode)
  {
    return makeLNURLFossa(secretATM, total, baseURLATM);
  }
  return makeLNURLLegacy(secretATM, total, baseURLATM);
}

// Function to seperate the LNURLDevice string in key, url and currency
String getValue(const String data, char separator, int index)
{
  int found = 0;
  int strIndex[] = { 0, -1 };
  const int maxIndex = data.length() - 1;

  for (int i = 0; i <= maxIndex && found <= index; i++)
  {
    if (data.charAt(i) == separator || i == maxIndex)
    {
      found++;
      strIndex[0] = strIndex[1] + 1;
      strIndex[1] = (i == maxIndex) ? i + 1 : i;
    }
  }
  return found > index ? data.substring(strIndex[0], strIndex[1]) : "";
}

// Display functions for specific display types

// ################################################################
// # Waveshare 1.54 inch e-Paper Display Modul with SPI Interface #
// ################################################################

void home_screen_waveshare_1_54()
{
  if (DEBUG_MODE)
    Serial.println("Home screen for Waveshare 1.54 inch display...");
  display.setRotation(1);
  display.setFullWindow();
  display.firstPage();

  display.setCursor(0, 10);
  display.setTextSize(3);
  display.setTextColor(GxEPD_BLACK, GxEPD_WHITE);
  display.println("Insert\nEuro coins\non the\nright\nside to\nstart ->");

  display.setCursor(0, 160);
  display.setTextSize(1);
  display.setTextColor(GxEPD_BLACK, GxEPD_WHITE);
  display.println("Prepare Lightning enabled Bitcoin\nwallet before starting!\n\nSupported coins:\n5 - 50 Cent and 1 - 2 Euro");
  display.nextPage();
  display.hibernate();
}

void show_inserted_amount_waveshare_1_54(String amount_in_euro)
{
  display.setRotation(1);
  display.setFullWindow();
  display.firstPage();

  display.setCursor(0, 4);
  display.setTextSize(2);
  display.setTextColor(GxEPD_BLACK, GxEPD_WHITE);
  display.println("Inserted amount:");

  display.setCursor(10, 90);
  display.setTextSize(3);
  display.setTextColor(GxEPD_BLACK, GxEPD_WHITE);
  display.println(amount_in_euro);

  display.setCursor(0, 160);
  display.setTextSize(2);
  display.setTextColor(GxEPD_BLACK, GxEPD_WHITE);
  display.println(" Press button\n once finished.");

  display.nextPage();
}

void qr_withdrawl_screen_waveshare_1_54(const char* qr_content)
{
  QRCode qrcoded;
  uint8_t qrcodeData[qrcode_getBufferSize(QR_VERSION)]; // 20 is "qr version"
  t_qrdata qr;

  // initialize qr code data
  qrcode_initText(&qrcoded, qrcodeData, QR_VERSION, 0, qr_content);
  qr.qr_size = qrcoded.size * 2;
  qr.start_x = (150 - qr.qr_size) / 2;
  qr.start_y = (150 - qr.qr_size) / 2;
  qr.module_size = 3;

  display.setRotation(1);
  display.setFullWindow();
  display.firstPage();
  // loop trough Y and X axis to draw the qr code rectangle by rectangle
  // 0, 0 is the top left of the screen
  for (qr.current_y = 0; qr.current_y < qrcoded.size; qr.current_y++)
  {
    for (qr.current_x = 0; qr.current_x < qrcoded.size; qr.current_x++)
    {
      if (qrcode_getModule(&qrcoded, qr.current_x, qr.current_y))
        display.fillRect(qr.start_x + qr.module_size * qr.current_x,
          qr.start_y + qr.module_size * qr.current_y,
          qr.module_size,
          qr.module_size,
          GxEPD_BLACK);
      else
        display.fillRect(qr.start_x + qr.module_size * qr.current_x,
          qr.start_y + qr.module_size * qr.current_y,
          qr.module_size,
          qr.module_size,
          GxEPD_WHITE);
    }
  }
  // draw the text messages on the screen
  display.setCursor(0, 4);
  display.setTextSize(2);
  display.setTextColor(GxEPD_BLACK, GxEPD_WHITE);
  display.println("Please scan QR:");  // top message
  display.setCursor(0, 170);
  display.setTextSize(2);
  display.setTextColor(GxEPD_BLACK, GxEPD_WHITE);
  display.println("Press the \nbutton to reset");  // bottom message
  display.nextPage();
  display.hibernate();
}

void clean_screen_waveshare_1_54()
{
  display.firstPage();
  display.nextPage();
  display.hibernate();
}

// ##############################################
// # Waveshare 2.7 inch e-ink display functions #
// ##############################################

void home_screen_waveshare_2_7()
{
  display.setRotation(1);
  display.setFullWindow();
  display.firstPage();

  display.setCursor(11, 20);
  display.setTextSize(2);
  display.setTextColor(GxEPD_BLACK, GxEPD_WHITE);
  display.println("Insert Euro coins\n on the right ->\n to start ATM");

  display.drawBitmap(172, 65, bitcoin_logo, 64, 64, GxEPD_BLACK);

  display.setCursor(12, 140);
  display.setTextSize(1);
  display.setTextColor(GxEPD_BLACK, GxEPD_WHITE);
  display.println("Prepare Lightning enabled Bitcoin\n  wallet before starting!\n  Supported coins: 5 - 50 Cent, 1 - 2 Euro");

  display.nextPage();
  display.hibernate();
}

void show_inserted_amount_waveshare_2_7(String amount_in_euro)
{
  display.setRotation(1);
  display.setFullWindow();
  display.firstPage();

  display.setCursor(11, 10);
  display.setTextSize(2);
  display.setTextColor(GxEPD_BLACK, GxEPD_WHITE);
  display.println("Inserted amount:");

  display.setCursor(20, 75);
  display.setTextSize(3);
  display.setTextColor(GxEPD_BLACK, GxEPD_WHITE);
  display.println(amount_in_euro);

  display.setCursor(11, 135);
  display.setTextSize(2);
  display.setTextColor(GxEPD_BLACK, GxEPD_WHITE);
  display.println("Press button\n once finished.");

  display.nextPage();
}

void qr_withdrawl_screen_waveshare_2_7(const char* qr_content)
{
  QRCode qrcoded;
  uint8_t qrcodeData[qrcode_getBufferSize(QR_VERSION)]; // 20 is "qr version"
  t_qrdata qr;

  qrcode_initText(&qrcoded, qrcodeData, QR_VERSION, 0, qr_content);
  qr.qr_size = qrcoded.size * 3;
  qr.start_x = (264 - qr.qr_size) / 2;
  qr.start_y = (176 - qr.qr_size) / 2;
  qr.module_size = 3;

  display.setRotation(1);
  display.setFullWindow();
  display.firstPage();
  for (qr.current_y = 0; qr.current_y < qrcoded.size; qr.current_y++)
  {
    for (qr.current_x = 0; qr.current_x < qrcoded.size; qr.current_x++)
    {
      if (qrcode_getModule(&qrcoded, qr.current_x, qr.current_y))
        display.fillRect(qr.start_x + qr.module_size * qr.current_x,
          qr.start_y + qr.module_size * qr.current_y, qr.module_size, qr.module_size, GxEPD_BLACK);
      else
        display.fillRect(qr.start_x + qr.module_size * qr.current_x,
          qr.start_y + qr.module_size * qr.current_y, qr.module_size, qr.module_size, GxEPD_WHITE);
    }
  }
  display.setCursor(11, 5);
  display.setTextSize(2);
  display.setTextColor(GxEPD_BLACK, GxEPD_WHITE);
  display.println("Please scan QR code:");  // top message

  display.setCursor(11, 155);
  display.setTextSize(2);
  display.setTextColor(GxEPD_BLACK, GxEPD_WHITE);
  display.println("Reset - press button");  // bottom message

  display.nextPage();
  display.hibernate();
}

void clean_screen_waveshare_2_7()
{
  display.firstPage();
  display.nextPage();
  display.hibernate();
}

// #########################################################
// # Waveshare 2.13 inch e-ink display (250x122) functions #
// #########################################################

void home_screen_waveshare_2_13()
{
  display.setRotation(1);
  display.setFullWindow();
  display.firstPage();

  display.setCursor(5, 5);
  display.setTextSize(2);
  display.setTextColor(GxEPD_BLACK, GxEPD_WHITE);
  display.println("LIGHTNING ATM");
  display.setCursor(3, 33);
  display.println("Insert coins");
  display.setCursor(3, 50);
  display.println("on the right");
  display.setCursor(3, 67);
  display.println("side to start");

  display.drawBitmap(180, 15, bitcoin_logo, 64, 64, GxEPD_BLACK);

  display.setCursor(0, 95);
  display.setTextSize(1);
  display.setTextColor(GxEPD_BLACK, GxEPD_WHITE);
  display.println(" Prepare Lightning enabled Bitcoin\n wallet before starting!\n Supported coins: 2 cent to 2 euro");
  display.nextPage();
  display.hibernate();
}

void show_inserted_amount_waveshare_2_13(String amount_in_euro)
{
  display.setRotation(1);
  display.setFullWindow();
  display.firstPage();

  display.setCursor(10, 4);
  display.setTextSize(2);
  display.setTextColor(GxEPD_BLACK, GxEPD_WHITE);
  display.println("Inserted amount:");

  display.setCursor(35, 45);
  display.setTextSize(3);
  display.setTextColor(GxEPD_BLACK, GxEPD_WHITE);
  display.println(amount_in_euro);

  display.setCursor(0, 85);
  display.setTextSize(2);
  display.setTextColor(GxEPD_BLACK, GxEPD_WHITE);
  display.println(" Press button\n to show QR code");

  display.nextPage();
}

void qr_withdrawl_screen_waveshare_2_13(const char* qr_content)
{
  QRCode qrcoded;
  uint8_t qrcodeData[qrcode_getBufferSize(QR_VERSION)]; // 20 is "qr version"
  t_qrdata qr;

  qrcode_initText(&qrcoded, qrcodeData, QR_VERSION, 0, qr_content);
  qr.qr_size = qrcoded.size * 2;
  qr.start_x = (230 - qr.qr_size) / 2;
  qr.start_y = (122 - qr.qr_size) / 2;
  qr.module_size = 2;

  display.setRotation(1);
  display.setFullWindow();
  display.firstPage();
  for (qr.current_y = 0; qr.current_y < qrcoded.size; qr.current_y++)
  {
    for (qr.current_x = 0; qr.current_x < qrcoded.size; qr.current_x++)
    {
      if (qrcode_getModule(&qrcoded, qr.current_x, qr.current_y))
        display.fillRect(qr.start_x + qr.module_size * qr.current_x,
          qr.start_y + qr.module_size * qr.current_y, qr.module_size, qr.module_size, GxEPD_BLACK);
      else
        display.fillRect(qr.start_x + qr.module_size * qr.current_x,
          qr.start_y + qr.module_size * qr.current_y, qr.module_size, qr.module_size, GxEPD_WHITE);
    }
  }
  display.setCursor(0, 20);
  display.setTextSize(2);
  display.setTextColor(GxEPD_BLACK, GxEPD_WHITE);
  display.println(" Scan\n\n  QR\n\n code");  // top message

  display.setCursor(181, 32);
  display.setTextSize(2);
  display.setTextColor(GxEPD_BLACK, GxEPD_WHITE);
  display.println("Reset");
  display.setCursor(181, 53);
  display.println("press");
  display.setCursor(176, 77);
  display.println("button");
  display.nextPage();
  display.hibernate();
}

void clean_screen_waveshare_2_13()
{
  display.firstPage();
  display.nextPage();
  display.hibernate();
}

// ###########################################################################
// # Waveshare 2.13 inch e-ink display (D) flex (yellow) (212x104) functions #
// ###########################################################################

void home_screen_waveshare_2_13_flex()
{
  display.setRotation(1);
  display.setFullWindow();
  display.firstPage();

  display.setCursor(5, 5);
  display.setTextSize(2);
  display.setTextColor(GxEPD_BLACK, GxEPD_WHITE);
  display.println("LIGHTNING ATM");
  display.setCursor(3, 25);
  display.println("Insert coins");
  display.setCursor(3, 42);
  display.println("on the right");
  display.setCursor(3, 59);
  display.println("side to start");

  display.drawBitmap(151, 8, bitcoin_logo, 64, 64, GxEPD_BLACK);

  display.setCursor(0, 80);
  display.setTextSize(1);
  display.setTextColor(GxEPD_BLACK, GxEPD_WHITE);
  display.println(" Prepare Lightning enabled Bitcoin\n wallet before starting!\n Supported coins: 2 cent to 2 euro");
  display.nextPage();
  display.hibernate();
}
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

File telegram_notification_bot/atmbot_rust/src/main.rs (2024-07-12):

use dotenv::dotenv;
use reqwest::blocking::Client;
use reqwest::header::{HeaderMap, HeaderValue};
use serde_json::Value;
use std::env;
use std::thread::sleep;
use std::time::Duration;

fn main() -> Result<(), Box<dyn std::error::Error>> {
    dotenv().ok();

    let url = env::var("LNBITS_URL").expect("URL not set in .env file");
    let min_balance: i64 = env::var("MIN_BALANCE")
        .expect("MIN_BALANCE not set in .env file")
        .parse()?;
    let refresh_interval: u64 = env::var("REFRESH_INTERVAL")
        .expect("REFRESH_INTERVAL not set in .env file")
        .parse()?;
    let api_key = env::var("LNBITS_API_KEY").expect("LNBITS_API_KEY not set in .env file");
    let bot_token =
        env::var("TELEGRAM_BOT_TOKEN").expect("TELEGRAM_BOT_TOKEN not set in .env file");
    let chat_id = env::var("TELEGRAM_CHAT_ID").expect("TELEGRAM_CHAT_ID not set in .env file");

    let mut previous_balance: i64 = 0;

    loop {
        match get_wallet_balance(&api_key, &url) {
            Ok(balance) => {
                let balance = balance / 1000;
                let difference = previous_balance - balance;

                if difference > 1 {
                    let message = format!("{} Sats have been withdrawn!", difference);
                    send_telegram_message(&bot_token, &chat_id, &message)?;
                } else if balance < min_balance {
                    let message = format!("Only {} Sats left in ATM, refill!", balance);
                    send_telegram_message(&bot_token, &chat_id, &message)?;
                }

                previous_balance = balance;
            }
            Err(_) => {
                println!("Balance check failed.");
                sleep(Duration::from_secs(3600));
                continue;
            }
        }

        sleep(Duration::from_secs(refresh_interval));
    }
}

fn get_wallet_balance(api_key: &str, url: &str) -> Result<i64, Box<dyn std::error::Error>> {
    let client = Client::new();
    let mut headers = HeaderMap::new();
    headers.insert("X-Api-Key", HeaderValue::from_str(api_key)?);

    let response = client.get(url).headers(headers).send()?;

    if response.status().is_success() {
        let data: Value = response.json()?;
        Ok(data["balance"]
            .as_i64()
            .expect("Failed to unwrap balance from returned JSON"))
    } else {
        Err(format!("Failed to get balance, status code: {}", response.status()).into())
    }
}

fn send_telegram_message(
    token: &str,
    chat_id: &str,
    message: &str,
) -> Result<(), Box<dyn std::error::Error>> {
    let telegram_url: String = format!("https://api.telegram.org/bot{}/sendMessage", token);
    let params = [("chat_id", chat_id), ("text", message)];

    let client = Client::new();
    client.post(telegram_url).form(&params).send()?;

    Ok(())
}

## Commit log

2023-11-26 cleanup stl files
    [Back_Lid_NORMAL_v1_NoSupp.stl, Back_Lid_THICKER_v1_NoSupp.stl, Case Magnet.stl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]
2023-11-29 shorten delay for reliability
    [main.cpp]
2023-12-01 Add wiring
2023-12-12 Update wiring
2023-12-16 add screen cover
    [transport_screen_cover.3mf]
2024-03-25 change led blinking and move logo to header
2024-04-08 Update pins in header
    Updated the pins in the header according to the changes in Readme by @AxelHamburch
    Periphery Pin ESP32 GPIO
    Button LED Pin (+) 21
    Mosfet PWM Pin 16
2024-04-11 case with hole
    [Case Magnet.stl, Front Magnet - with 12 mm hole.stl, Logo Backplate Magnet.stl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]
2024-04-11 docu for case update
2024-04-15 Add Waveshare ESP32 Driver Board
2024-04-15 Waveshare ESP32 Driver board
2024-04-23 Waveshare ESP32 wiring and construction
2024-06-04 add coin catcher
    [CCatch v3.stl]
